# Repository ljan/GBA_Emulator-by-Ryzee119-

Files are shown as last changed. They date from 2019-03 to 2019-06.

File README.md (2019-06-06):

# GBA RaspberryPi Zero  

## Display:  
https://sudomod.com/forum/viewtopic.php?f=22&t=2312  
https://sudomod.com/forum/viewtopic.php?f=25&t=5614  
https://sudomod.com/forum/viewtopic.php?f=22&t=5854&p=60773#p60709  
https://learn.adafruit.com/adafruit-2-8-pitft-capacitive-touch/downloads  

Screen | Raspberry Pi 3 or zero 
------------ | -------------
SDI(MOSI) | Pin 19 (GPIO10) 
SDO(MISO) | PIN 21 (GPIO9) 
SCK | Pin 23 (GPIO11) 
CS | Pin 24 (GPIO8) 
DC | Pin 22 (GPIO25) 
RESET | Pin 26 (GPIO7) 
LED | Pin 12 (GPIO18) 
VCC | Pin 1 (3.3V) 
GND | Pin 20 (GND) 

## Audio:  
http://www.ti.com/lit/ds/symlink/lm4875.pdf  

## Power:  
https://hackaday.io/project/19035-zerophone-a-raspberry-pi-smartphone/log/69596-a-guide-on-powering-pi-zero-directly-from-liion-batteries  

## Credits:  
> This was originally designed by /u/Ryzee
> Originally posted on Reddit here:
> https://www.reddit.com/r/DIY/comments/4zbqwr/this_is_my_attempt_at_making_a_portable_emulator/
> 
> Build Photos:
> http://imgur.com/a/kjFmS
> 
> I am releasing these design files in good faith that people will use them to learn something about electronics and maybe bring > an old Gameboy Advance (GBA) back to life.
> 
> I don’t want to see people taking this design and knocking it off for a quick buck.
> If you don’t want to deal with all this work another redditor /u/Flav0r has designed something quite similar to this. http://gamepieadvance.com/ I understand he may be working on DIY Kits.

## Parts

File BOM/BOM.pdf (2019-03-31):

Bill of Materials based on my GBA mod. By /u/Ryzee
http://imgur.com/a/kjFmS
https://www.reddit.com/r/DIY/comments/4zbqwr/this_is_my_attempt_at_making_a_portable_emulator/

## Build at your own risk!

Qty Value | Device | Parts | Digikey part
3 100k | RES SMD 100K OHM 1% 1/8W 0805 | R5, R6, R14 | RMCF0805FT100KCT-ND (https://www.digikey.com.au/product-detail/en/stackpole-electronics-inc/RMCF0805FT100K/RMCF0805FT100KCT-ND/1942491)
6 100n | CAP CER 0.1UF 25V X7R 0805 | C1, C3, C11, C12, C16, C17 | 1276-1099-1-ND (https://www.digikey.com.au/product-detail/en/samsung-electro-mechanics-america-inc/CL21B104KACNNNC/1276-1099-1-ND/3889185)
7 10u | CAP CER 10UF 10V X7R 0805 | C2, C5, C6, C13, C14, C15, C18 | 1276-2934-1-ND (https://www.digikey.com.au/short/39j4v8)
1 1k | RES SMD 1K OHM 1% 1/8W 0805 | R4 | RMCF0805FT1K00CT-ND (https://www.digikey.com.au/product-detail/en/stackpole-electronics-inc/RMCF0805FT1K00/RMCF0805FT1K00CT-ND/1942370)
1 220n | CAP CER 0.22UF 16V X7R 0805 | C4 | 1276-1284-1-ND (https://www.digikey.com.au/product-detail/en/samsung-electro-mechanics-america-inc/CL21B224KOCNNNC/1276-1284-1-ND/3889370)
2 270R | RES SMD 270 OHM 1% 1/8W 0805 | R8, R15 | RMCF0805FT270RCT-ND (https://www.digikey.com.au/product-detail/en/stackpole-electronics-inc/RMCF0805FT270R/RMCF0805FT270RCT-ND/1942346)
2 27R | RES SMD 27 OHM 1% 1/8W 0805 | R2, R3 | RMCF0805FT27R0CT-ND (https://www.digikey.com.au/product-detail/en/stackpole-electronics-inc/RMCF0805FT27R0/RMCF0805FT27R0CT-ND/5049791)
1 430k | RES SMD 430K OHM 1% 1/8W 0805 | R9 | P430KCCT-ND (http://www.digikey.com.au/product-detail/en/panasonic-electronic-components/ERJ-6ENF4303V/P430KCCT-ND/1746869)
1 330n | CAP CER 0.33UF 50V X7R 0805 | C8 | 1276-1123-1-ND (https://www.digikey.com.au/product-detail/en/samsung-electro-mechanics-america-inc/CL21B334KBFNNNE/1276-1123-1-ND/3889209)
1 3R9 | RES SMD 3.9 OHM 1% 1/8W 0805 | R10 | RMCF0805FT3R90CT-ND (https://www.digikey.com.au/product-detail/en/stackpole-electronics-inc/RMCF0805FT3R90/RMCF0805FT3R90CT-ND/2418397)
1 4.7uH | FIXED IND 4.7UH 1.72A 82 MOHM | L4 | 732-1021-1-ND (https://www.digikey.com.au/product-detail/en/wurth-electronics-inc/744042004/732-1021-1-ND/1639082)
1 47k | PVZ3A473C01R00 | R11 (Use 10K version if out of stock) | 490-7795-1-ND (https://www.digikey.com.au/product-detail/en/bourns-inc/PVZ3A473C01R00/490-7795-1-ND/4358063)
3 47uF | CAP ALUM 47UF 20% 16V SMD | C9, C10 | P15090CT-ND (https://www.digikey.com.au/product-detail/en/panasonic-electronic-components/EEE-FT1C470AR/P15090CT-ND/2796927)
1 600 Ohm | FERRITE BEAD 600 OHM 0805 1LN | L1 | 240-2390-1-ND (https://www.digikey.com.au/product-detail/en/laird-signal-integrity-products/MI0805K601R-10/240-2390-1-ND/806750)
2 620R | RES SMD 620 OHM 1% 1/8W 0805 | R12, R13 | 1276-5260-1-ND (https://www.digikey.com.au/product-detail/en/samsung-electro-mechanics-america-inc/RC2012F621CS/1276-5260-1-ND/3968232)
1 976k | RES 976K OHM 1/8W 1% 0805 | R7 | 311-976KCRCT-ND (https://www.digikey.com.au/product-detail/en/yageo/RC0805FR-07976KL/311-976KCRCT-ND/731162)
1 AZV321 | IC OPAMP GEN PURP SOT25 | U7 | AZV321KTR-G1DICT-ND (https://www.digikey.com.au/product-detail/en/diodes-incorporated/AZV321KTR-G1/AZV321KTR-G1DICT-ND/4505335)
2 DFLS130L | DIODE SCHOTTKY 30V 1A POWERDI123 | D1, D2 | DFLS130LDICT-ND (https://www.digikey.com.au/product-detail/en/diodes-incorporated/DFLS130L-7/DFLS130LDICT-ND/673203)
1 XZMDKVG54W-4 LED GREEN/RED DUAL LED CLEAR 0805 SMD | D3 | 1497-1182-1-ND (https://www.digikey.com.au/product-detail/en/sunled/XZMDKVG54W-4/1497-1182-1-ND/4745895)
1 FT230X | IC USB SERIAL BASIC UART 16SSOP | U2 | 768-1154-5-ND (https://www.digikey.com.au/product-detail/en/ftdi-future-technology-devices-international-ltd/FT230XS-U/768-1154-5-ND/3749469)
1 LM4875 | IC AMP AUDIO PWR 1W MONO 8SOIC | U4 | 296-35282-1-ND (https://www.digikey.com.au/product-detail/en/texas-instruments/LM4875MX-NOPB/296-35282-1-ND/3738990)
1 MCP1642B-ADJ | IC REG BOOST ADJ 0.8A SYNC 8MSOP | U3 | MCP1642B-ADJI/MS-ND (https://www.digikey.com.au/product-detail/en/microchip-technology/MCP1642B-ADJI-MS/MCP1642B-ADJI-MS-ND/5125100)
1 MIC7211 | IC COMPARATOR R-R INPUT SOT23-5 | U6 | 576-1318-1-ND (https://www.digikey.com.au/product-detail/en/microchip-technology/MIC7211YM5-TR/576-1318-1-ND/771922)
1 IRLML6401TRPBF MOSFET P-CH 12V 4.3A SOT-23 | Q1 | IRLML6401PBFCT-ND (https://www.digikey.com.au/product-detail/en/infineon-technologies/IRLML6401TRPBF/IRLML6401PBFCT-ND/812509)
1 CLS0231MA-1-L152SPEAKER 8OHMS .5W 23MM 6" LEADS | SP1 | 102-1553-ND (https://www.digikey.com.au/product-detail/en/cui-inc/CLS0231MA-1-L152/102-1553-ND/1630867)
1 MIC5365-2.8YC5-TRIC REG LDO 2.8V 0.15A SC70-5 | U5 | 576-3187-1-ND (https://www.digikey.com.au/product-detail/en/microchip-technology/MIC5365-2.8YC5-TR/576-3187-1-ND/1868224)
1 FLAT FLEX | HF18U-02-ND CABLE FLAT FLEX 18POS 1MM 2" (https://www.digikey.com.au/product-detail/en/parlex-usa-llc/100R18-51B/HF18U-02-ND/273663) | - | HF18U-02-ND (https://www.digikey.com.au/product-detail/en/parlex-usa-llc/100R18-51B/HF18U-02-ND/273663)
1 GBA_TFT_CON | CONN FFC BOTTOM 18POS 1.00MM R/A | TFT1 | 609-1911-1-ND (https://www.digikey.com.au/product-detail/en/amphenol-fci/SFW18R-1STE1LF/609-1911-1-ND/1003200)
1 TFT DISPLAY | 3.2" 18P SPI TFT ILI9341 320x240 | - | Aliexpress (https://www.aliexpress.com/item/3-2-inch-18P-SPI-TFT-LCD-Screen-with-Touch-panel-ILI9341-Drive-IC-240-320/32556379195.html)
1 27k | Nintendo VOLUME ADJUST POT | R1 | Taken out of old GBA
1 HEADPHONE | Nintendo HEADPHONE | X2 | Taken out of old GBA
2 L+R SHOULDER | Nintendo BUTTON | SW1 | Taken out of old GBA
1 LINK_SOCKET | Nintendo LINK_SOCKET | X1 | Taken out of old GBA
1 PWR_SWITCH | Nintendo PWR_SWITCH | SW3 | Taken out of old GBA
1 RPI-ZERO | RPI-ZERO | U1 | -
2 AA Batteries | Recommendation is ENERGIZER L91 Lithium or equivalent good quality lithium AA's | | -
1 GBA Link cable | Needs to be modified with a USB male connector on one end | | eBay
1 TFT_ADAPTER_PCBADAPTER PCB FOR TFT FLAT FLEX CABLE | - | OHSPark Direct Link (https://oshpark.com/shared_projects/9tH3I87q)

NOTE: THESE ARE ALL BARE MINIMUM QUANTITIES. I RECOMMEND GETTING SPARES BECAUSE SMALL COMPONENTS CAN FLY AWAY AND THEY'RE USUALLY LOST FOREVER

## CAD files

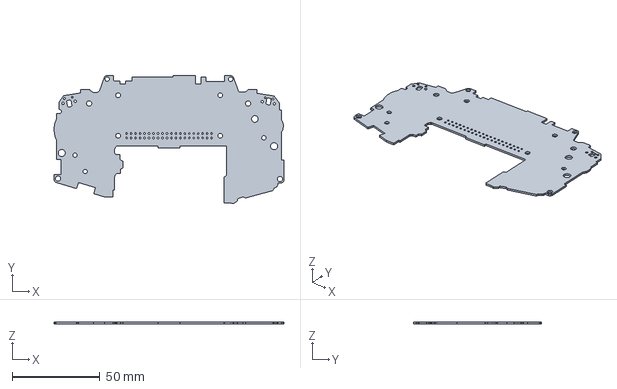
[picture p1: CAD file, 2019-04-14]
PCB/KiCAD/GBA_EMU.step
130.7 x 72.9 x 1.00 mm

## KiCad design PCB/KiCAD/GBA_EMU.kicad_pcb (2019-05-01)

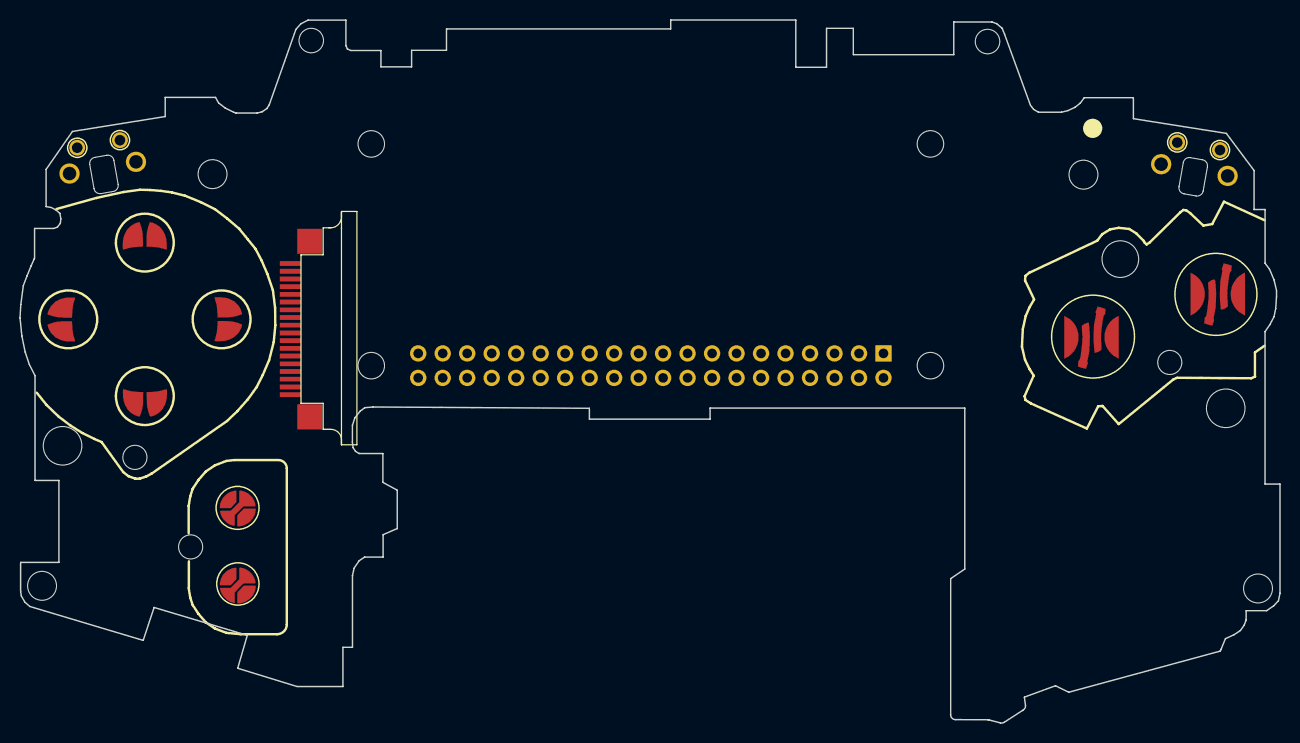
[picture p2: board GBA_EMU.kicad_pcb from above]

Board: 2 copper layers, 130.7 x 72.9 mm, 19 parts (0 on the bottom side), 9 nets, no tracks yet.

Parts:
@HOLE0, @HOLE1, @HOLE2, @HOLE3, @HOLE4, @HOLE5, @HOLE6, @HOLE7, @HOLE8, @HOLE9, @HOLE10, @HOLE11: (no value)
J1: Raspberry_Pi_2_3; Raspberry_Pi_Zero_Socketed_THT_FaceDown_MountingHoles
SW_AB1: SW_DIP_x02; AB_BUTTON
SW_DPAD1: SW_DIP_x04; D-PAD
SW_L1: SW_DIP_x01; SHOULDER_BUTTON
SW_R1: SW_DIP_x01; SHOULDER_BUTTON
SW_SS1: SW_DIP_x02; START_SELECT_BUTTON
U1: ILI3941; 18PIN-0.8MM

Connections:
+3V3: J1.1, J1.17, U1.9
+5V: J1.2, J1.4, U1.10
GND: J1.6, J1.9, J1.14, J1.20, J1.25, J1.30, J1.34, J1.39, SW_AB1.3, SW_AB1.4, SW_DPAD1.5, SW_DPAD1.6, SW_DPAD1.7, SW_DPAD1.8, SW_L1.2, SW_R1.2, SW_SS1.3, SW_SS1.4, U1.1, U1.8
TFT_CS: J1.24, U1.5
TFT_DC: J1.18, U1.4
TFT_MISO: J1.21, U1.7
TFT_MOSI: J1.19, U1.6
TFT_RESET: J1.22, U1.2
TFT_SCK: J1.23, U1.3

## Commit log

2019-03-31 reorganisiert
    moved files in seperate folders
    [BOM.xlsx, GBA_EMU.brd, GBA_EMU.sch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]
2019-04-04 cleaned pcb and schematic
    keept outlines of pcb and onyl some parts
    [GBA_EMU.brd, GBA_EMU.sch, TFT_ADAPTER.brd]
2019-04-05 cleaned pcb
    removed most parts and marked positions
    [GBA_EMU.brd, GBA_EMU.sch]
2019-04-05 converted to KiCAD
    [GBA_EMU.kicad_pcb, GBA_EMU.sch, GBA_EMU.step]
2019-04-10 Imported Foodprints
    Button Foodprints from https://github.com/AEFeinstein/gbaZero
2019-04-10 imported footprints
    button footprints from https://github.com/AEFeinstein/gbaZero
    [GBA_EMU.kicad_pcb, GBA_EMU.sch, GBA_EMU.step]
2019-04-11 Create .gitignore
    template for eagle and kicad
2019-04-14 LCD Connection
    https://github.com/juj/fbcp-ili9341#if-you-wired-the-display-to-the-pi-yourself
    https://sudomod.com/forum/viewtopic.php?f=22&t=5854
    Screen<------------>Raspberry Pi 3 or zero
    LED<-------------->Pin 12 (GPIO18)
    SCK<-------------->Pin 23 (GPIO11)
    SDI(MOSI)<----->Pin 19 (GPIO10)
    DC<--------------->Pin 22 (GPIO24)
    RESET<----------->Pin 26 (GPIO25)
    CS<----------------->Pin 24 (GPIO8)
    [GBA_EMU.step, _saved_GBA_EMU.sch]
2019-04-14 PWM Audio
    [GBA_EMU.sch]
2019-05-01 Audio, LCD, Buttons
    [GBA_EMU.kicad_pcb, GBA_EMU.sch]
